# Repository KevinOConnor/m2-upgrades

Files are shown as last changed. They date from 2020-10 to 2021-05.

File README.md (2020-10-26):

This repository documents upgrades to a
[Makergear M2 printer](http://makergear.wikidot.com/m2). The printer
was one of the original M2 printer models - purchased in 2012 as a
kit, it came with a V3A extruder, two separate "power bricks" (one
19V, one 12V), RAMBo v1.0d electronics with 1/8th microstepping A4984
drivers, and a Z axis stepper with 30 Ohm coils.

# Upgrades

## Firmware

I use the [Klipper firmware](https://www.klipper3d.org/).

## Spool holder

I removed all the spool holder hardware from the M2 and use a separate
[spool holder in a ziplock bag](https://github.com/KevinOConnor/zipspool).

## Upgrade to 24V

There are four important steps to upgrade the printer to 24V:
* [Hotend and extruder upgrade](power_24v/extruder.md)
* [Power supply upgrade](power_24v/psu.md)
* [Heated bed upgrade](power_24v/bed.md)
* [Electronics upgrade](power_24v/maestro.md)

## Z Max endstop

Homing away from the bed is an important upgrade for the M2. The newer
[M2 endstop bracket](https://github.com/MakerGear/M2/blob/master/Printed%20Parts/STL/Hardware%20Revision%20E/Z%20Max%20Endstop%20Bracket.STL)
works well.

## Bed glass spacers

I use ["spacers"](bed_spacer/bed_spacer.md) to improve the rubber
contact of the glass bed.

## Tool holder

I use this [tool holder](https://www.thingiverse.com/thing:132171).

## Raspberry Pi holder

I [mount a Raspberry Pi and Raspberry Pi camera](rpi/rpi.md) to the M2
frame.

## LED case light

I added [LED lights](case_light/case_light.md) to the top of the M2
frame.

## Z Stepper

The printer came with a Z stepper that has 30 Ohm coils.  This high
resistance places a limit on the amount of current that can pass
through the stepper.  In order to compensate for this, I set the
tmc2208 `run_current=0.566` (RMS) and use a `hold_current=0.300`.
(Using a higher current setting would result in poor micro-stepping
precision.)

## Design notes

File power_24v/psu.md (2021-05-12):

This documents an upgrade of the Makergear M2 power supply to 24V.

I printed the power supply holder at
https://www.thingiverse.com/thing:4491723 .  Printed in ABS with
0.200mm layer height.

I purchased a "MEAN WELL LRS-350-24 350W 24V power supply" ($29 from
Amazon).  It is my understanding that there are forgeries of the MEAN
WELL power supplies, so although I purchased from Amazon I made sure
it was "sold by Amazon" and not from their marketplace.

I purchased an "IEC320 socket" ($12 for 2-pack from Amazon) and made
sure that it included wires that were already crimped.

To assist in the wiring I also purchased a pack of "fork spade wire
connectors" ($7 for 100-pack from Amazon).  Otherwise I reused
existing wires to connect the new power supply to the electronics
board.

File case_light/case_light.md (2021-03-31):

This documents describes an LED case light upgrade to the Makergear
M2.

In order to have better visibility of the printed part during
printing, I added LEDs to the top of the M2 frame.  The LEDs are
underneath the X axis aluminum plate and shine down towards the print
area.

I designed an [LED holder](m2-led-holder.stl).  It is printed in white
ABS with 0.200mm layer height.  (The white ABS helps diffuse the
light.)  The holder is screwed to the frame using the two existing M4
screws that secure the top aluminum plate to the steel frame.

For the LEDs, I purchased a "24V white LED strip without power supply"
($9 for 5 meters / 300 LEDs from Amazon).  I cut five 200mm sections
from the strip and then soldered wires to them.  I soldered those five
pairs of wires into one pair of wires and then connected that to the
"E1 mosfet" on the electronics.

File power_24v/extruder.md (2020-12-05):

This documents an upgrade of the Makergear M2 hotend and extruder.

## Extruder motor

Separate from the 24V upgrade, the extruder motor that came with my
original M2 broke.  It appears that movement of the X carriage
eventually caused one of the internal stepper motor wires to become
loose and short with other wires.

I replaced the stepper motor and gearbox with a "Usongshine Nema 17
with 5.18:1 Planetary Gearbox" ($27 from Amazon).

## Extruder mount

The original plastic part that mounts the extruder motor to the X
carriage was of low quality.  It broke while attempting to adjust the
hotend.  The plastic was very brittle (I could crumble it with my
fingers) and appears to have been printed with ~20% infill.

I printed a new motor mount from:
https://github.com/MakerGear/M2/blob/master/Printed%20Parts/STL/M2%20Extruder%20Motor%20Mount%20r3.STL

I printed it in ABS with 0.200mm layer height and 80% infill.

## Hotend upgrade to 24V

I purchased a 24V E3D v6 hotend ($55 from Printed Solid).  I printed
the "New_E3D_v6_Extruder_2.0_Plain_no_Support.stl" found at
https://www.thingiverse.com/thing:495756/files .  Printed in ABS
with 0.200mm layer height and 80% infill.  I also purchased some 2mm
files ($9 from Amazon) and filed down the filament path.

The E3D fan and heater wires are long enough to reach the M2
electronics, but I preferred having plugs by the hotend.  (In
contrast, the E3D thermistor came with a "microfit connector" that was
already compatible with the M2 wiring.)  For the new fan, I cut the
wires and used a crimping tool to connect a "dupont connector" that
was compatible with the existing wiring.  For the heater, I cut the
E3D heater wires, cut the M2 "microfit connector" from the existing
wires, and then soldered on an XT30 connector ($9 for 10-pairs from
Amazon).  I then used the existing heater wiring.

## Part cooling fan upgrade to 24V

I printed the "E3D_30_mm_Duct.stl" and "E3D_40_mm_Duct.stl" found at
https://www.thingiverse.com/thing:1165614/files .  Printed in ABS
with 0.200mm layer height.  To assemble, I purchased a "40mm WINSINN
24V fan" ($19 for 5-pack from Amazon) along with "1/4 inch x 1/16 inch
magnets" ($7 for 25-pack from Amazon).

The plug on the new fan was not compatible with the existing M2 fan
plug.  I cut the wires and used a crimping tool to connect a "dupont
connector" so that I could use the existing plug and wiring.

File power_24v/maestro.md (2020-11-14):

This documents an upgrade of the Makergear M2 electronics.

I used a Duet2 Maestro board for the electronics.  In order to improve
cooling, I mounted the electronics vertically on the outside of the M2
frame.

I designed a [holder for the board](m2-maestro.stl) and a
[cover](m2-maestro-cover.stl).  Printed in PETG with 0.200mm layer
height and 20% infill.

As part of the new electronics, it was necessary to redo the "wire
harness".  That involved cutting nearly all the zip ties on the
existing wires, connecting the wires to the new electronics, applying
new zip ties to bundle the wires, and then reapplying the wire
shrouds.

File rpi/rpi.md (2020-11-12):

This documents an upgrade of the Makergear M2 so that one can mount a
Raspberry Pi and Raspberry Pi camera module to it.

I printed the Raspberry Pi case at:
https://www.thingiverse.com/thing:2342050 along with brackets from:
https://www.thingiverse.com/thing:2342080 .  Printed in PETG
with 0.200mm layer height and 20% infill.  I mounted the case
vertically along the right side of the M2 frame (just under the X
stepper motor).

For the Raspberry Pi camera module, I designed a
[camera holder](m2-rpi-camera.stl).  Printed in PETG with 0.200mm
layer height and 20% infill.  The holder is mounted outside the M2
steel frame on the upper right side (behind the X stepper).

Caveats:

* The camera picks up some glare from the LED lights and it's position
  isn't able to see the nozzle when the X carriage is near the X
  maximum.

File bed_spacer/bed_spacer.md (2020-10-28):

This documents an upgrade of the glass grip on the Makergear M2 heated
bed platform.

The rubber pads on the four corners of the M2 Y-axis "spider" mount
did not do a good job of gripping the glass plate.

I designed small [spacers](m2-bed-rubber-spacer.stl) so the L-shaped
rubber pad would be at a higher position and the glass would sit
between the L-shaped rubber pad instead of on top of it.  Printed in
PETG with 0.200mm layer height and 80% infill.  I use M3x16mm screws
(instead of M3x14mm) and arrange the bed corners so that (from bottom
to top) there is the aluminum spider, the rubber square pad, the
plastic spacer, the L-shaped rubber pad, a metal washer, and then the
M3 screw.

Note that the spacer height was adjusted for the thicker cork board on
my heated bed platform after performing the 24V upgrade.

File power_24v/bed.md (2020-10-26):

This documents an upgrade of the Makergear M2 heated bed to 24V.

The original heated bed used a 200mm x 200mm "kapton tape" heater
applied to the underside of an aluminum heat spreader.

To upgrade to 24V I stripped and cleaned the aluminum heat spreader.
Using an xacto knife I was able to cut between the aluminum heat
spreader and kapton tape (along the side of the heat spreader).  I was
then able to peel off the kapton tape heater (which also removed most
of the cork insulation).  I also used the xacto knife to remove the
remaining cork board.  I unscrewed the thermistor and set it aside (I
reused it later in the build).  To clean the adhesive from the heat
spreader I alternatively soaked it in isoprophyl alcohol and scrubbed
it with a "green scotch-brite pad".

I purchased a "200x200mm 24V 200W Silicone Heater" ($31 from Gulfcoast
Robotics).  Since I was not going to use the thermistor that came with
the heater, I snipped the wires to the new thermistor, used an xacto
knife to carefully remove it from the silicone heater, and then I also
used the xacto knife to carefully scrape off the remaining adhesive on
the silicone heater.  I then attached this heater to the back of the
cleaned aluminum heat spreader.  (There are videos online describing
how to attach a silicone heater without introducing air pockets.)  I
then screwed the original thermistor on to the heat spreader.

To insulate the silicone heater, I purchased some "2mm cork sheets
with self-adhesive" ($12 for 8-pack of 30cm x 21cm sheets from
Amazon).  Since the new silicone heater is thicker than the original
kapton tape heater, I first attached two 25mm strips of cork on the
sides of the heat spreader (cutting out for the thermistor).  I then
placed a single cork sheet over the entire back of the heat spreader.

The original heater used a "Deans connector" for quick disconnect.  I
liked this setup, so I soldered off the wires from the existing plug,
and then cut, stripped, and soldered the new silicone heater wires to
it.  This allowed me to reuse the existing bed heater and thermistor
wiring.

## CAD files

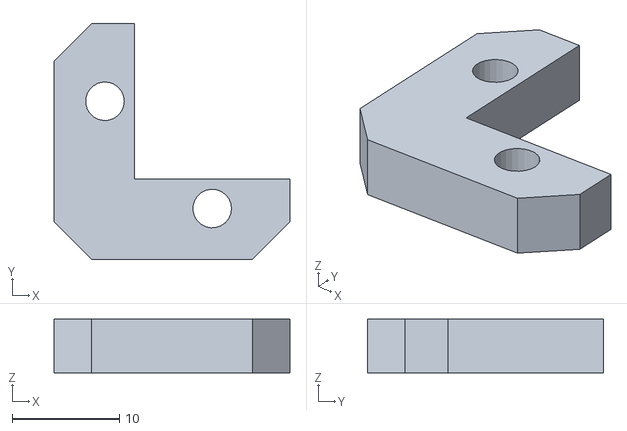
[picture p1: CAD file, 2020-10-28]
bed_spacer/m2-bed-rubber-spacer.stl
22.0 x 22.0 x 5.00

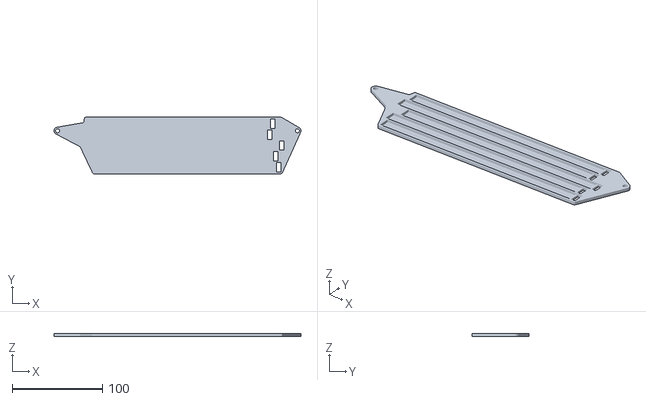
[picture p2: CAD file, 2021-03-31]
case_light/m2-led-holder.stl
273.0 x 62.5 x 3.00

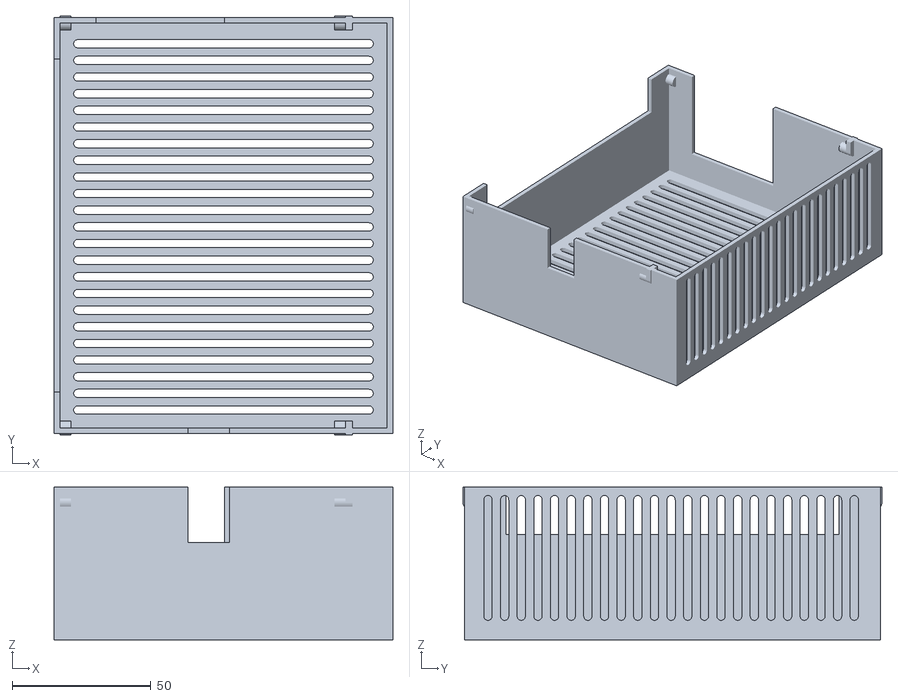
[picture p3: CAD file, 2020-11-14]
power_24v/m2-maestro-cover.stl
122.0 x 151.0 x 55.0

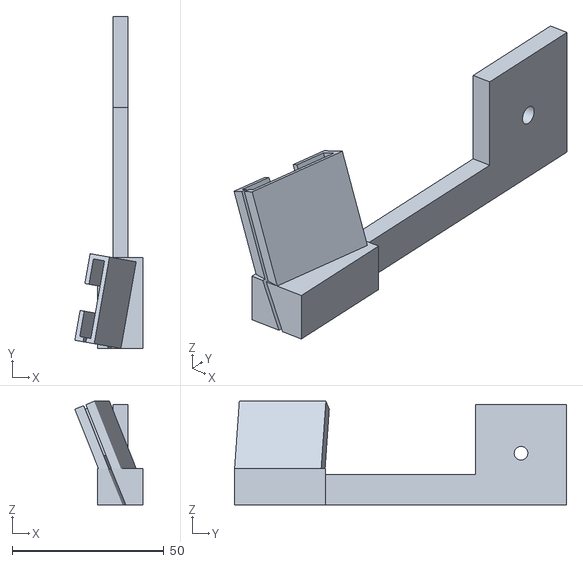
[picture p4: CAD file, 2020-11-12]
rpi/m2-rpi-camera.stl
22.5 x 109.5 x 34.1

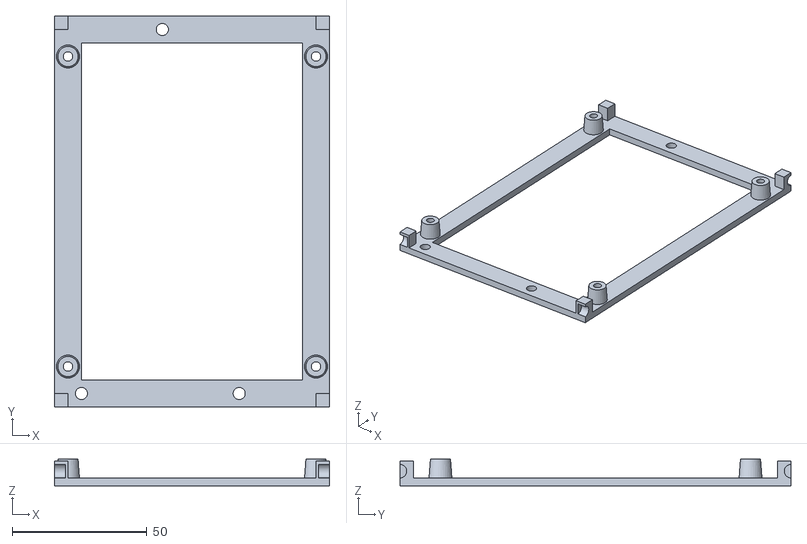
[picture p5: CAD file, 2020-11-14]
power_24v/m2-maestro.stl
102.0 x 145.0 x 10.0

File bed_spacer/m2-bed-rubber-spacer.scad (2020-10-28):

// M2 bed spacers for rubber pads
//
// Copyright (C) 2020  Kevin O'Connor <kevin@koconnor.net>
//
// This file may be distributed under the terms of the GNU GPLv3 license.

// Misc measurements:
//   - Glass plate is 4mm thick.
//   - Aluminum heat spreader is 3mm thick.
//   - Cork board is 2mm thick.
//   - L-shaped rubber is 4mm thick.
//   - Bottom rubber is 3mm thick.

// Spacer external dimensions
bigx=22;
bigy=22;
cutx=14.5;
cuty=14.5;
cornershort=3.5;
height = 5.0;

// Screw location and size
screwx=14.75;
screwy=4.75;
screwr=1.8;

$fs = .5;

module spacer() {
    module lrubber() {
        polygon([[0, cornershort], [cornershort, 0],
                 [bigx-cornershort, 0], [bigx, cornershort],

                 [bigx, bigy-cuty], [bigx-cutx, bigy-cuty], [bigx-cutx, bigy],

                 [cornershort, bigy], [0, bigy-cornershort] ]);
    }

    module lrubberwithholes() {
        difference() {
            lrubber();
            translate([screwx, screwy])
                circle(r=screwr);
            translate([screwy, screwx])
                circle(r=screwr);
        }
    }

    linear_extrude(height = height)
        lrubberwithholes();
}

spacer();

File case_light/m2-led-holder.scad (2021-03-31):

// LED strip holder for M2
//
// Copyright (C) 2020  Kevin O'Connor <kevin@koconnor.net>
//
// This file may be distributed under the terms of the GNU GPLv3 license.

// Room at top for 2.5 inches width == 63.5mm
// Top frame screws measure 10 7/16 inches apart == 265mm
//  (10 11/16 - 4/16 == 10 7/16)

// Right Screw is ~9mm from steel frame; bed is ~19mm from steel frame.
// Screw ~9.5mm from edge.

// LED strip is 10mm wide by 1mm high.  Each section is 100mm long.

// Longest diagonal print on M2 is 320mm (sqrt(200**2 + 250**2))

plate_height = 3;
outside_wall = 2;
screw_holder = 8;
screw_dia = 4.5;
m2_rscrew_x = 265;
x_idler_offset_x = 26;
x_idler_offset_y1 = 30;
x_idler_offset_y2 = 4;
led_frame_x = 40;
led_frame_y = 15;
led_frame_length = 200;
led_frame_height = .6;
led_width = 10 + .5;
light_width = 4;
light_height = 0.4;
led_tracks = 5;
spacing = 100 / 6;
track_offsets = [2*spacing/5, 3*spacing/5, -spacing/5, spacing/5, 0];
led_bump_length = 2;
led_bump_height = 1;
led_wire_length = 5;
led_wall = 1.5;
slack = 1;
CUT = 0.01;
$fs = .5;

module led_plate() {
    module cyl(d, x, y) {
        translate([x, y])
            cylinder(d=d, h=plate_height);
    }
    led_frame_width = (led_width + led_wall) * led_tracks;
    frame_width = led_frame_width - led_wall + 2 * outside_wall;
    //echo(frame_width);
    hull_dia = 3;
    hull_left = led_frame_x;
    hull_right = led_frame_x + led_frame_length + led_bump_length + led_wire_length;
    hull_y1 = led_frame_y - hull_dia/2;
    hull_y2 = led_frame_y - frame_width + hull_dia/2;
    module plate() {
        hull() {
            cyl(screw_holder, 0, 0);
            cyl(hull_dia, x_idler_offset_x, hull_y1 - x_idler_offset_y1);
            cyl(hull_dia, hull_left, hull_y1 - x_idler_offset_y2);
        }
        hull() {
            cyl(hull_dia, x_idler_offset_x, hull_y1 - x_idler_offset_y1);
            cyl(hull_dia, x_idler_offset_x, hull_y1 - x_idler_offset_y1);
            cyl(hull_dia, x_idler_offset_x + 5, hull_y1);
            cyl(hull_dia, hull_left, hull_y1);
            cyl(hull_dia, hull_left, hull_y2);
            cyl(hull_dia, hull_right, hull_y1);
            cyl(hull_dia, hull_right, hull_y2);
            cyl(screw_holder, m2_rscrew_x, 0);
        }
    }
    module led_track() {
        // Main channel to hold leds
        cube([led_frame_length, led_width, plate_height]);
        // Open space for light
        light_z = light_height-led_frame_height;
        translate([0, (led_width - light_width)/2, light_z])
            cube([led_frame_length, light_width, plate_height+99+CUT]);
        // Space for led wires
        bump_z = plate_height - (led_frame_height+led_bump_height);
        translate([led_frame_length - CUT, 0, bump_z])
            cube([led_bump_length+2*CUT, led_width, plate_height]);
        translate([led_frame_length + led_bump_length, 0, -99])
            cube([led_wire_length, led_width, 99 + plate_height + 2*CUT]);
    }
    track_y = led_frame_y - outside_wall - led_width;
    difference() {
        plate();
        translate([0, 0, -CUT])
            cylinder(d=screw_dia, h=plate_height + 2*CUT);
        translate([m2_rscrew_x, 0, -CUT])
            cylinder(d=screw_dia, h=plate_height + 2*CUT);
        for (i=[0:led_tracks-1]) {
            y = track_y - i * (led_width + led_wall);
            translate([led_frame_x - track_offsets[i], y, led_frame_height])
                led_track();
        }
    }
}

led_plate();

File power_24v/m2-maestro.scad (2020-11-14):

// Holder for Duet2 Maestro board on side of M2 printer
//
// Copyright (C) 2020  Kevin O'Connor <kevin@koconnor.net>
//
// This file may be distributed under the terms of the GNU GPLv3 license.

// M2 side screw locations:
//  z=11.5mm: +0mm, +145mm; z=41: +10mm, +67.5mm; z=70mm: +96mm, +145mm
// screw hole is 4.6mm wide; m4 screw is 3.86mm wide; head is 6.96mm dia
// m3 hex nut is 5.4mm across; m3 screw is 2.88mm wide; head is 5.38mm dia

// Duet board is 123x100mm. Screws at:
//  4,4 ; 4,119 ; 96,119 ; 96,4

plate_height = 3;
plate_offset_x = 1;
plate_offset_y = 11;
plate_width = 100 + 2 * plate_offset_x;
plate_length = 133 + plate_offset_y + 1;
plate_border = 10;
standoff_height = 10;
standoff_top_width = 7.5;
standoff_bot_width = 9;
standoff_screw_dia = 3.5;
standoff_screw_hex = 6.235 + .1;
standoff_screw_positions = [ [4, 4], [4, 119], [96, 119], [96, 4] ];
printer_screw_dia = 4.5;
printer_screw_xoffset = 10 - 11.5;
printer_screw_yoffset = 5;
printer_screw_positions = [ [11.5, 0], [70, 0], [41.5, 135] ];
notch_length = 4;
notch_radius = 2.5;
cover_height = 55;
cover_thick = 2;
cover_extra_width = 15;
slack = 1;
CUT = 0.01;
$fs = .5;

//
// Back Plate
//

module back_plate() {
    // Simple hollow rectangular plate to mount to M2 steel frame
    module plate() {
        difference() {
            cube(size=[plate_width, plate_length, plate_height]);
            translate([plate_border, plate_border, -CUT])
                cube(size=[plate_width - 2*plate_border,
                           plate_length - 2*plate_border, plate_height + 2*CUT]);
        }
    }

    // Notches to hold cover
    module notch() {
        difference() {
            translate([0, 0, plate_height-CUT])
                cube(size=[notch_length + 1, 2*notch_radius,
                           2.5*notch_radius+CUT]);
            translate([-CUT, 0, plate_height + notch_radius])
                rotate([0, 90, 0])
                    cylinder(h=notch_length + 2*CUT, r=notch_radius);
        }
    }

    // Pillars to hold duet2 to plate
    module screw_standoff(pos) {
        translate(pos)
            translate([plate_offset_x, plate_offset_y])
                cylinder(h=standoff_height, d1=standoff_bot_width,
                         d2=standoff_top_width);
    }

    // Cutout space for duet2 screw
    module screwcut_standoff(pos) {
        module hex() {
            d1 = standoff_screw_hex + .2;
            d2 = standoff_screw_hex;
            d3 = 0;
            cylinder(h=standoff_height - 2.5 + CUT, d1=d1, d2=d2, $fn=6);
            translate([0, 0, standoff_height - 2.5])
                cylinder(h=1 + CUT, d1=d2, d2=d3, $fn=6);
        }
        translate(pos)
            translate([plate_offset_x, plate_offset_y, -CUT]) {
                cylinder(h=standoff_height + 2*CUT, d=standoff_screw_dia);
                rotate([0, 0, 90])
                    hex();
            }
    }

    // Cutout space for M2 mounting screw
    module screwcut_printer(pos) {
        translate(pos)
            translate([printer_screw_xoffset, printer_screw_yoffset, -CUT])
                cylinder(h=plate_height + 2*CUT, d=printer_screw_dia);
    }

    module full_plate() {
        plate();
        for (pos=standoff_screw_positions)
            screw_standoff(pos);
        // Cover notches
        notch();
        translate([plate_width, 0, 0])
            mirror([1, 0, 0])
                notch();
        translate([0, plate_length, 0])
            mirror([0, 1, 0])
                notch();
        translate([plate_width, plate_length, 0])
            mirror([0, 1, 0])
                mirror([1, 0, 0])
                    notch();
    }

    difference() {
        full_plate();
        for (pos=standoff_screw_positions)
            screwcut_standoff(pos);
        for (pos=printer_screw_positions)
            screwcut_printer(pos);
    }
}

//
// Cover
//

module cover() {
    cover_width = plate_width + 2*cover_thick + cover_extra_width + slack;
    cover_length = plate_length + 2*cover_thick + slack;
    module box() {
        inner_width = cover_width - 2*cover_thick;
        inner_length = cover_length - 2*cover_thick;
        difference() {
            cube(size=[cover_width, cover_length, cover_height]);
            translate([cover_thick, cover_thick, cover_thick])
                cube(size=[inner_width, inner_length, cover_height]);
        }
    }
    module board_guide(pos) {
        guide_height = plate_height + notch_radius;
        guide_width = notch_radius;
        guide_length = notch_radius;
        translate(pos)
            translate([0, -guide_length, cover_height - guide_height]) {
                cube(size=[guide_width, 2*guide_length, guide_height]);
                translate([0, notch_radius, 0])
                    rotate([0, 90, 0])
                        cylinder(h=guide_length, r=notch_radius);
            }
    }
    module notch(pos) {
        h = cover_height - plate_height - notch_radius;
        translate(pos)
            translate([0, -CUT, h])
                rotate([0, 90, 0])
                    cylinder(h=notch_length + CUT, r=notch_radius);
    }
    module box_with_notches() {
        box();

        board_end_x = plate_width + cover_thick + slack;
        board_end_y = plate_length + cover_thick + slack;
        board_guide([board_end_x, cover_thick, 0]);
        board_guide([board_end_x, board_end_y, 0]);

        notch([cover_thick, cover_thick, 0]);
        notch([board_end_x - notch_length, cover_thick, 0]);
        notch([cover_thick, board_end_y, 0]);
        notch([board_end_x - notch_length, board_end_y, 0]);
    }

    vent_dia = 3;
    vent_offset = 6.5 + cover_thick;
    vent_space = 6;
    module vent_hole(pos1, pos2, rot) {
        hull() {
            translate(pos1)
                rotate(rot)
                    translate([0, 0, -CUT])
                        cylinder(h=cover_thick + 2*CUT, d=vent_dia);
            translate(pos2)
                rotate(rot)
                    translate([0, 0, -CUT])
                        cylinder(h=cover_thick + 2*CUT, d=vent_dia);
        }
    }

    module lid_holes() {
        // Vent holes
        min_x = vent_offset;
        max_x = cover_width - vent_offset;
        min_y = vent_offset;
        max_y = cover_length - vent_offset;
        for (y=[min_y:vent_space:max_y])
            vent_hole([min_x, y], [max_x, y], [0, 0, 0]);
    }
    module top_holes() {
        // Vent holes
        min_z = vent_offset;
        max_z = cover_height - (plate_height + vent_dia/2);
        min_y = vent_offset;
        max_y = cover_length - vent_offset;
        rot = [0, 270, 0];
        for (y=[min_y:vent_space:max_y])
            vent_hole([cover_width, y, min_z], [cover_width, y, max_z], rot);
    }
    module bottom_holes() {
        // Large air hole at bottom of case
        min_y = 15;
        hole_length = cover_length - 2*min_y;
        hole_height = cover_thick + standoff_height + 5;
        translate([-CUT, min_y, cover_height - hole_height])
            cube(size=[cover_thick+2*CUT, hole_length, hole_height+CUT]);
    }
    module front_holes() {
        // USB plug
        usb_center_x = 100 - 47.250 + plate_offset_x + cover_thick;
        usb_plug_width = 15;
        usb_plug_height = 10;
        hole_x = usb_center_x - usb_plug_width/2;
        hole_z = cover_height - standoff_height - usb_plug_height;
        hole_height = cover_height - hole_z;
        translate([hole_x, -CUT, hole_z])
            cube(size=[usb_plug_width, cover_thick + 2*CUT, hole_height + CUT]);
    }
    module back_holes() {
        // Wiring block
        wiring_max_x = 100 - 41.7 + plate_offset_x + cover_thick;
        wiring_min_x = 15;
        hole_y = cover_length - cover_thick;
        hole_width = wiring_max_x - wiring_min_x;
        hole_height = standoff_height + 30;
        translate([wiring_min_x, hole_y - CUT, cover_height-hole_height])
            cube(size=[hole_width, cover_thick + 2*CUT, hole_height + CUT]);
    }

    difference() {
        box_with_notches();

        lid_holes();
        top_holes();
        bottom_holes();
        front_holes();
        back_holes();
    }

    //translate([cover_thick + slack/2, cover_thick + slack/2, 35])
    //    back_plate();
}

//
// Object selection
//

back_plate();
//cover();

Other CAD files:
rpi/m2-rpi-camera.scad

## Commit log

2020-10-26 Initial description of M2 upgrades
    [m2-bed-rubber-spacer.scad, m2-bed-rubber-spacer.stl, m2-led-holder.scad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]
2020-10-27 rpi: Printed and mounted new Raspberry Pi case
    [m2-rpi-back.scad]
2020-10-28 bed_spacer: Update bed spacers for thicker cork board (due to 24V upgrade)
    [m2-bed-rubber-spacer.scad, m2-bed-rubber-spacer.stl]
2020-11-11 rpi: Rework camera mount
    Replace camera mount with a new in-frame camera holder.
    [m2-rpi-camera.scad, m2-rpi-camera.stl]
2020-11-12 rpi: Use arm to extend rpi camera mount past toolhead
    The old mount under the m2 frame could collide with the bed. Move the
    camera outside the frame by attaching it to an arm.
    [m2-rpi-camera.scad, m2-rpi-camera.stl]
2020-11-13 extruder: Update docs to note motor mount now printed in ABS
    The PLA motor mount failed and I had to reprint in ABS.
2020-11-14 maestro: Update case and add case cover
    Extend the case back plate so that it is screwed to the M2 frame at
    three locations.
    Add a case cover.
    [m2-maestro-cover.stl, m2-maestro.scad, m2-maestro.stl]
2020-12-02 case_light: Updated and printed case light holder in ABS
    The petg version of the case light holder melted. Reo the print in
    opaque ABS.
    [m2-led-holder.scad, m2-led-holder.stl]
2020-12-05 extruder: The PETG fan shroud melted - reprinted in ABS
2021-03-31 case_light: Rework light holder using white ABS with added diffusion
    [m2-led-holder.scad, m2-led-holder.stl]
2021-05-12 psu: Reprinted power supply holder in ABS
